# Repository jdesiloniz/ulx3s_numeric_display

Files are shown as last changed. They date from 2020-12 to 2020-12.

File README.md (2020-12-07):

# ulx3s_numeric_display

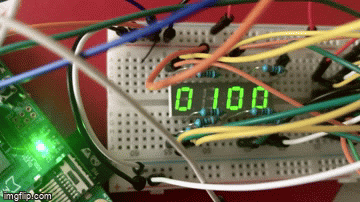
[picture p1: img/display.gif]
Running on a breadboard


The goal of this project is to be able to use 4-digit 7-segment displays with the [ULX3S FPGA board](https://ulx3s.github.io/) as an easy and quick method of debugging/data display. OLED screens are really convenient but they require more complex logic and memory buffers to contain the graphical data, so I think having these displays as an alternative for simple debugging can help a lot for quick iteration and debugging.

## Design

In order to be able to interface one of these displays you need 12 pins, so the design uses two 74HC164N serial-to-parallel ICs to be able to interface all pins using just 4 data signals (+ VCC/GND). Segment data and digit data are generated at a pre-defined rate (by default in this design - 400Hz) and fed to these chips that rely them to the display. Only some transistors and resistors are required besides these connections to make it all work.

This design is meant to work with a common-anode display by default. Using common-cathode display is possible though, just changing the value of `COMMON_ANODE` to `1'b0` in the appropiate modules.

## Components

- `clk_divider`: configurable clock divider used to drive the 74HC164N (at 6MHz) and the refresh rate for the LED display.
- `shifter`: a shifter module that's able to perform multiple shift/rotation operations.
- `reset`: simple reset controller.
- `wb_hc164`: module that interfaces communication with **74HC164N** ICs using a simplified Wishbone bus.
- `led_display_controller`: module to drive the LED display through two 74HC164N. Users can place raw segment data for each one of the digits.
- `numeric_led_display_controller`: small wrapper on top of the previous module. Users just need to pass a 16 bit number and it'll be displayed in hexadecimal form by the LED display.
- `top`: an example of using these, displaying a second counter.

## Board

Warning: the PCB hasn't been tested yet, but the design has been found to work using a breadboard. I'll update this as soon as I get it built and running :). If in any case you want to play this, KiCAD design files are [available here](board).

The board is intended to be used with a common-anode display. Using a common-cathode display is possible but it'd require to change the layout of the transistors (to use NPN ones).

## Use

You're free to use any of these modules for your own projects, modify them or whatever. But it'd be nice if you at least drop a mention! Also, I can't guarantee that this won't break anything... it didn't in my case! :D

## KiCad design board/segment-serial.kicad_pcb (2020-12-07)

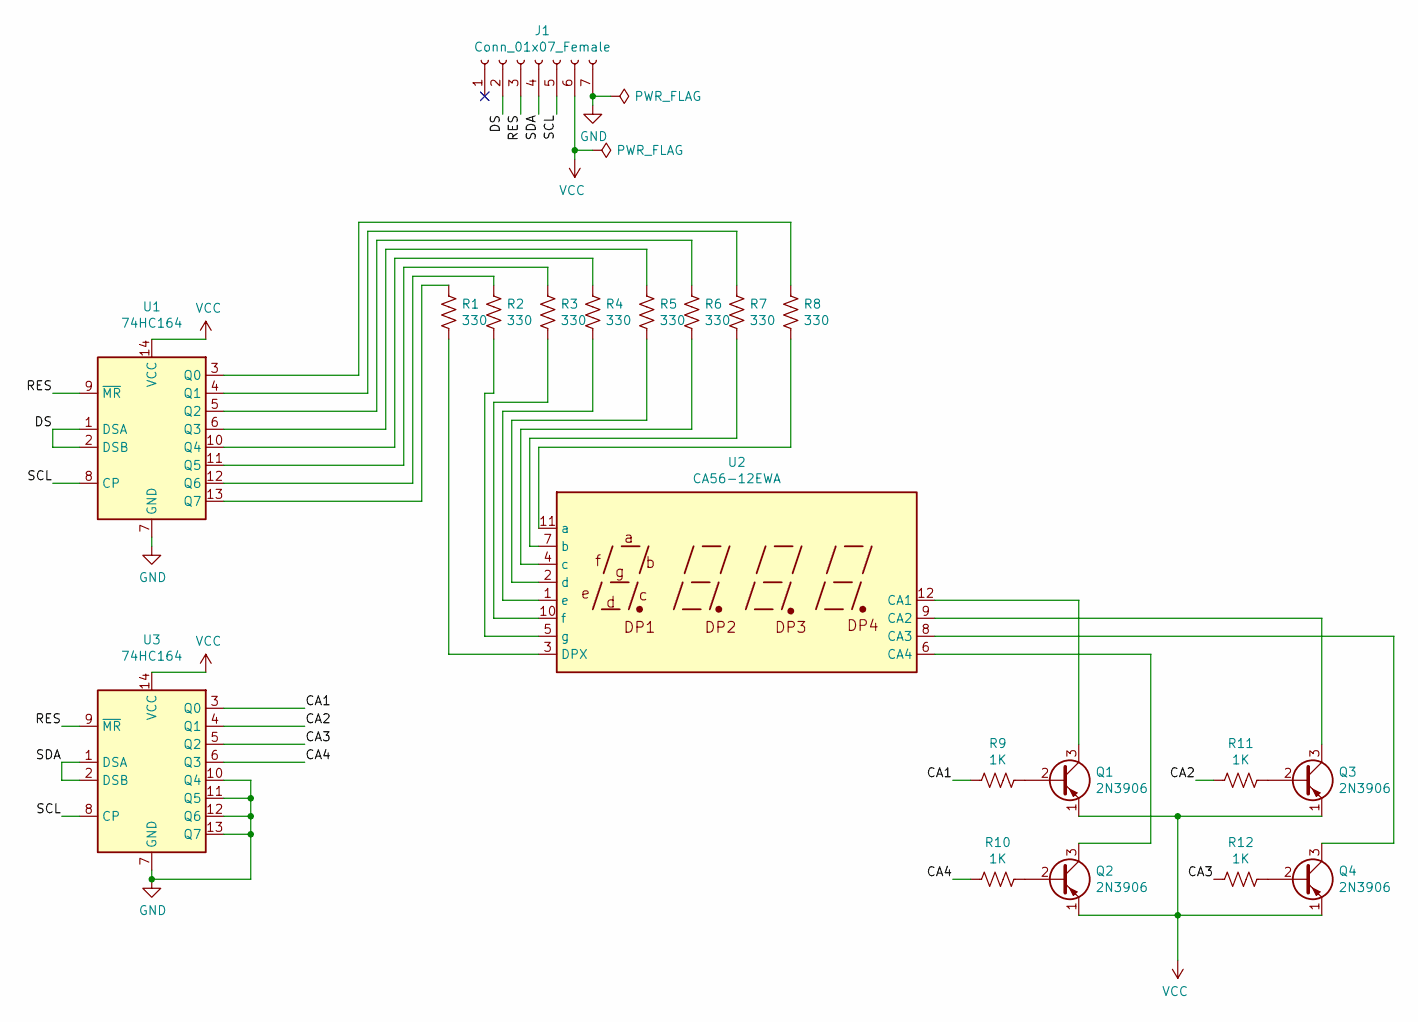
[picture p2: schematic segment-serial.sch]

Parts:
J1: Conn_01x07_Female; PinHeader_1x07_P2.54mm_Vertical
Q1, Q2, Q3, Q4: 2N3906; TO-92_Inline
R1, R2, R3, R4, R5, R6, R7, R8: 330; R_Axial_DIN0207_L6.3mm_D2.5mm_P7.62mm_Horizontal
R9, R10, R11, R12: 1K; R_Axial_DIN0207_L6.3mm_D2.5mm_P7.62mm_Horizontal
U1, U3: 74HC164; DIP-14_W7.62mm
U2: CA56-12EWA

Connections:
/CA1: R9.2, U3.3 (Q0)
/CA2: R11.2, U3.4 (Q1)
/CA3: R12.2, U3.5 (Q2)
/CA4: R10.2, U3.6 (Q3)
/DS: J1.2, U1.1 (DSA), U1.2 (DSB)
/RES: J1.3, U1.9 (~MR), U3.9 (~MR)
/SCL: J1.5, U1.8 (CP), U3.8 (CP)
/SDA: J1.4, U3.1 (DSA), U3.2 (DSB)
GND: J1.7, U1.7 (GND), U3.7 (GND), U3.10 (Q4), U3.11 (Q5), U3.12 (Q6), U3.13 (Q7)
unnamed: Q1.2 (B), R9.1
unnamed: Q1.3 (C), U2.12 (CA1)
unnamed: Q2.2 (B), R10.1
unnamed: Q2.3 (C), U2.6 (CA4)
unnamed: Q3.2 (B), R11.1
unnamed: Q3.3 (C), U2.9 (CA2)
unnamed: Q4.2 (B), R12.1
unnamed: Q4.3 (C), U2.8 (CA3)
unnamed: R1.1, U2.3 (DPX)
unnamed: R1.2, U1.13 (Q7)
unnamed: R2.1, U2.5 (g)
unnamed: R2.2, U1.12 (Q6)
unnamed: R3.1, U1.11 (Q5)
unnamed: R3.2, U2.10 (f)
unnamed: R4.1, U1.10 (Q4)
unnamed: R4.2, U2.1 (e)
unnamed: R5.1, U1.6 (Q3)
unnamed: R5.2, U2.2 (d)
unnamed: R6.1, U1.5 (Q2)
unnamed: R6.2, U2.4 (c)
unnamed: R7.1, U1.4 (Q1)
unnamed: R7.2, U2.7 (b)
unnamed: R8.1, U1.3 (Q0)
unnamed: R8.2, U2.11 (a)
VCC: J1.6, Q1.1 (E), Q2.1 (E), Q3.1 (E), Q4.1 (E), U1.14 (VCC), U3.14 (VCC)

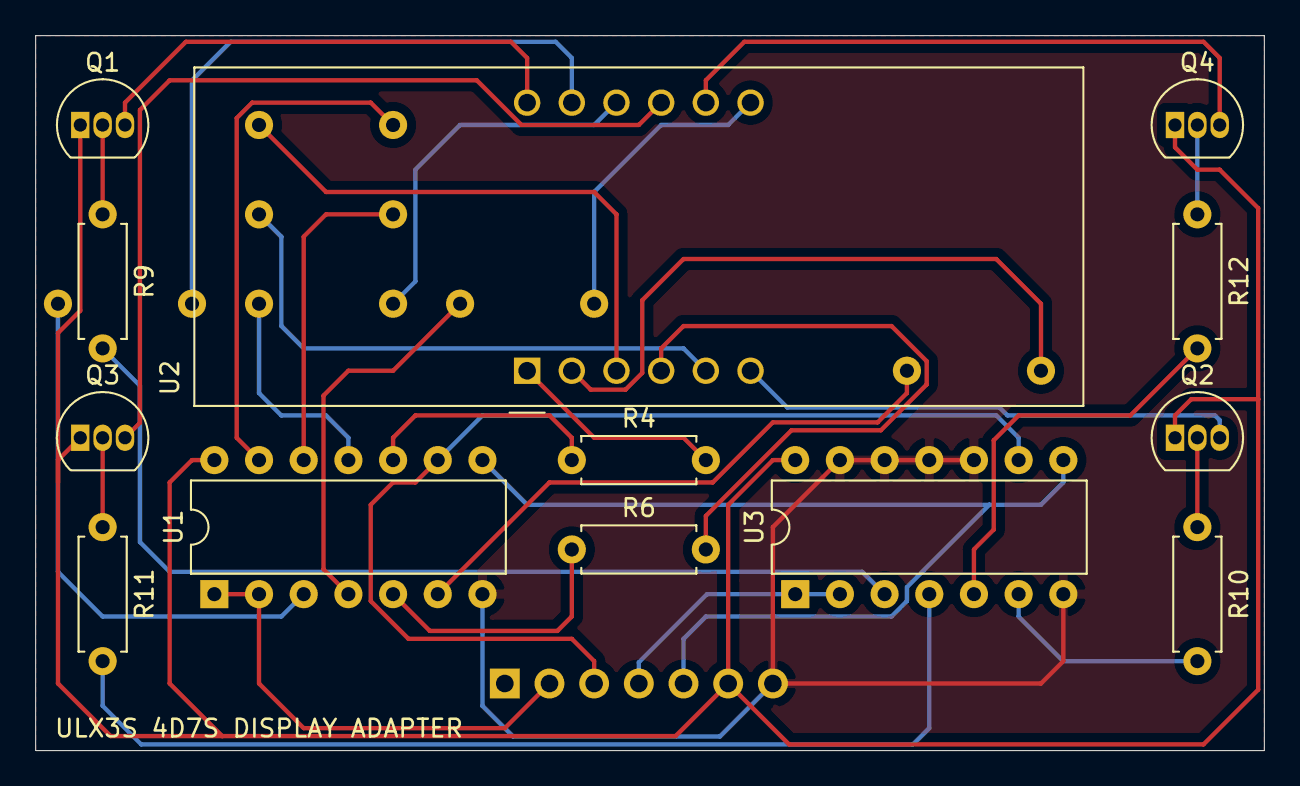
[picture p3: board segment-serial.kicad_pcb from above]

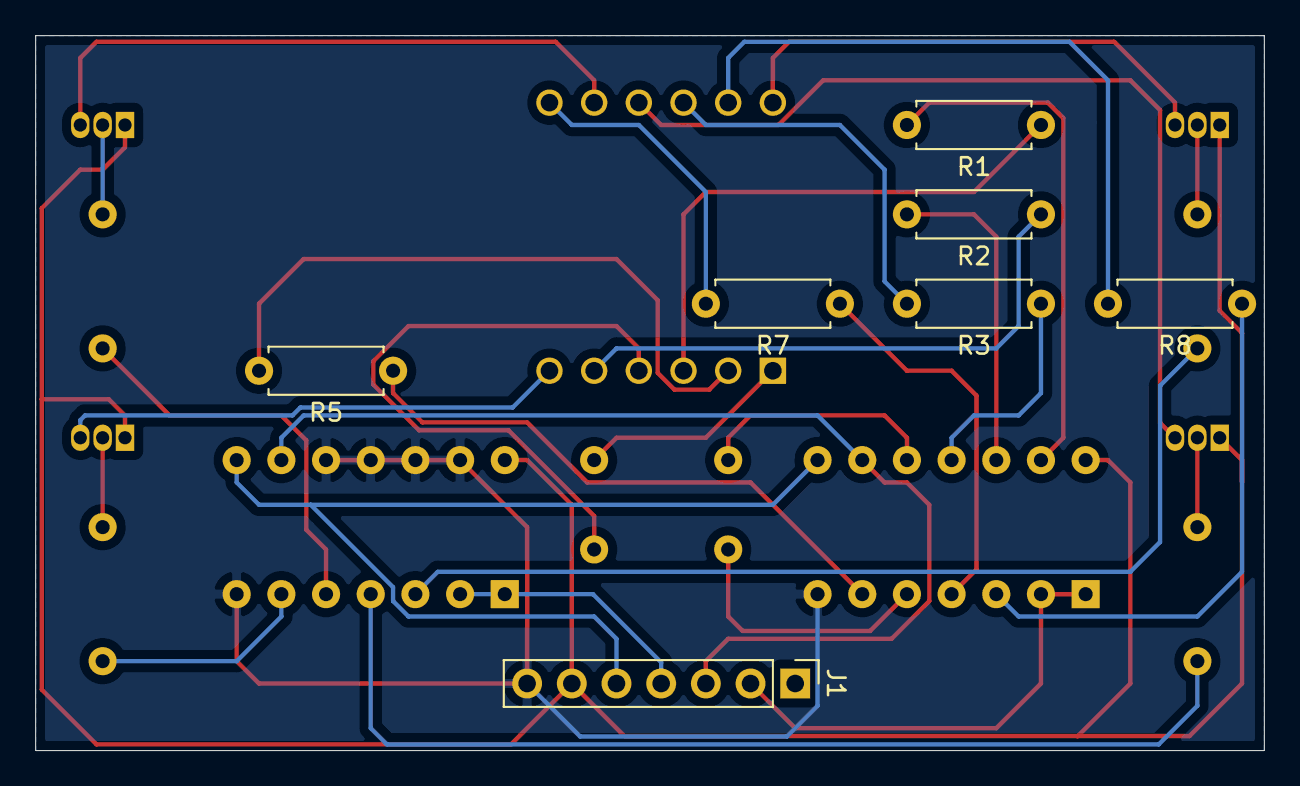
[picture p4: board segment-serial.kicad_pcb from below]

Board: 2 copper layers, 69.8 x 40.6 mm, 20 parts (7 on the bottom side), 34 nets.

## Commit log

2020-12-05 Fixed issues with LED display controller - added simulation code
2020-12-05 Added led counter
2020-12-07 Fixed issue with reset signal in led controller
2020-12-07 Fixing issue with unconnected pins in U3
    [segment-serial.kicad_pcb, segment-serial.sch]
2020-12-07 Fixing broken formal verification tests after changes to fix combinational loops
    [segment-serial.kicad_pcb]
